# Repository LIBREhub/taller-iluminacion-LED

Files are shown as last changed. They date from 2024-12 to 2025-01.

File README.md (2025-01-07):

# Taller de iluminación LED

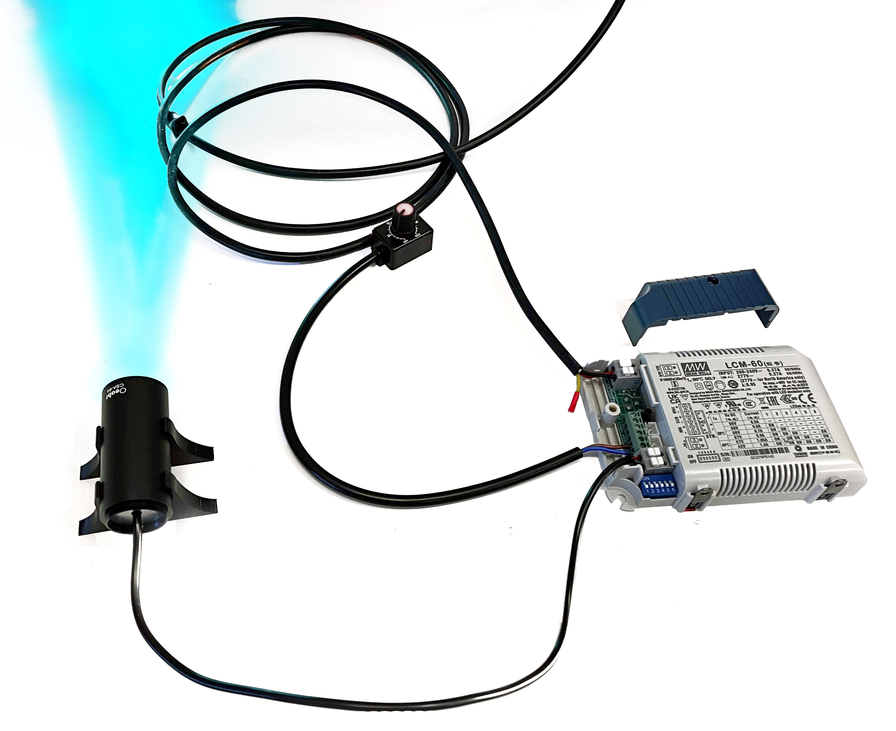
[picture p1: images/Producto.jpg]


##Arma el tuyo:
* [Componentes](Componentes.md)
* [Instrucciones de armado](Instrucciones.md)

---

##Siguenos en redes:
* [YouTube](https://www.youtube.com/@librehub), 
* [LinkedIn](https://www.linkedin.com/company/92802424), 
*   [Instagram](https://www.instagram.com/wenzellab), 
*  [Printables](https://www.printables.com/@WenzelLab/models) &  [Thingiverse](https://www.thingiverse.com/libre-hub/designs)
* [LIBREhub website](https://librehub.github.io),  
* [IIBM website](https://ingenieriabiologicaymedica.uc.cl/en/people/faculty/799-vicente-parot)

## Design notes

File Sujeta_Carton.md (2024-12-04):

#Plástico sujetador de cartón



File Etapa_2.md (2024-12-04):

##Etapa 2: Conexiones al driver

En esta etapa conectarás el cable AC del enchufe al driver y el dimmer al driver, como
muestra este diagrama:

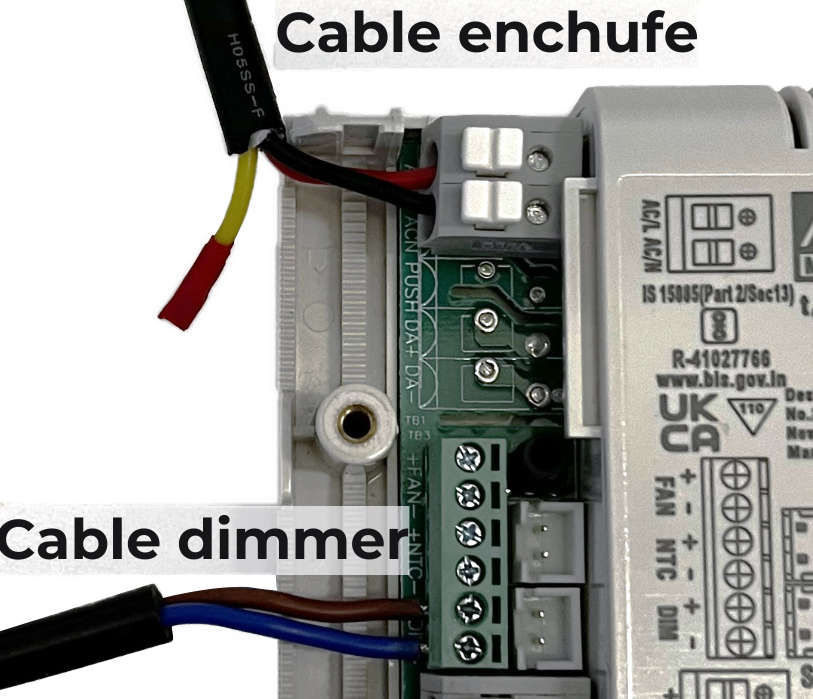
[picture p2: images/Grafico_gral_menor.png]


Como podrás notar, el cable amarillo queda libre, así que le pondremos cinta aislante por
seguridad, aunque luego le pondremos la tapa al driver de igual manera. Luego de construir
el módulo LED en la siguiente etapa, lo conectaremos al driver en la etapa 4.

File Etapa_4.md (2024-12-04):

##Etapa 4: Construir el módulo LED

Para esta etapa necesitaras pelar el cable más delgado por ambos extremos. En uno dejarás
aproximadamente 2 centímetros expuestos de los cables rojo y negro que están dentro,
exponiendo sus conductores para conectarlos al driver posteriormente. En el otro extremo,
dejarás 5 centímetros y con el conductor expuesta. Este último extremo es el que debes
introducir a la perforación del disipador de calor.

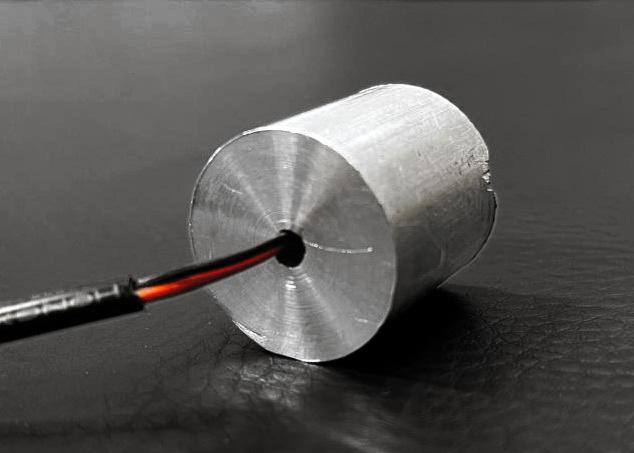
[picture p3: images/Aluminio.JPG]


Luego, vamos a soldar el LED a los cables que sobresalen del disipador. **Es muy importante
que respetes la polaridad al momento de soldar**, siguiendo este diagrama (rojo =
positivo; negro = negativo).

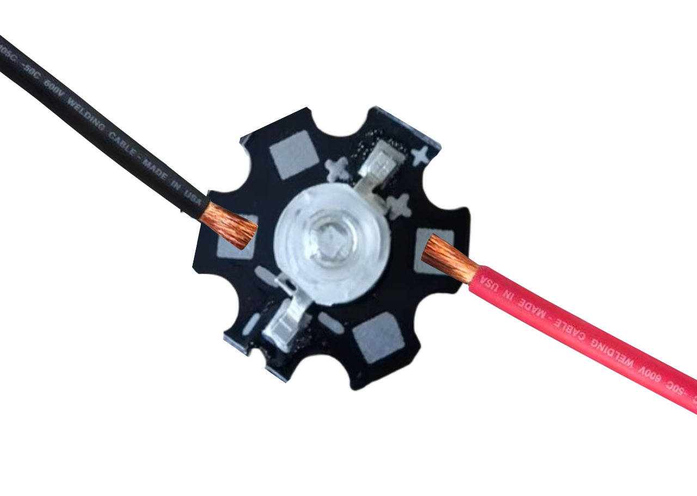
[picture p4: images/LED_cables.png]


Para soldar los cables necesitarás un cautín y estaño, los cuales te brindaremos en ese
momento.

Una vez soldado el LED, debes pegar la cinta termoconductora azul de doble contacto al
disipador, para luego pegar el LED. Para ello, cortarás dos pedazos con la forma que
sobresale fuera de la ranura del disipador, tal como se indica en la siguiente foto:

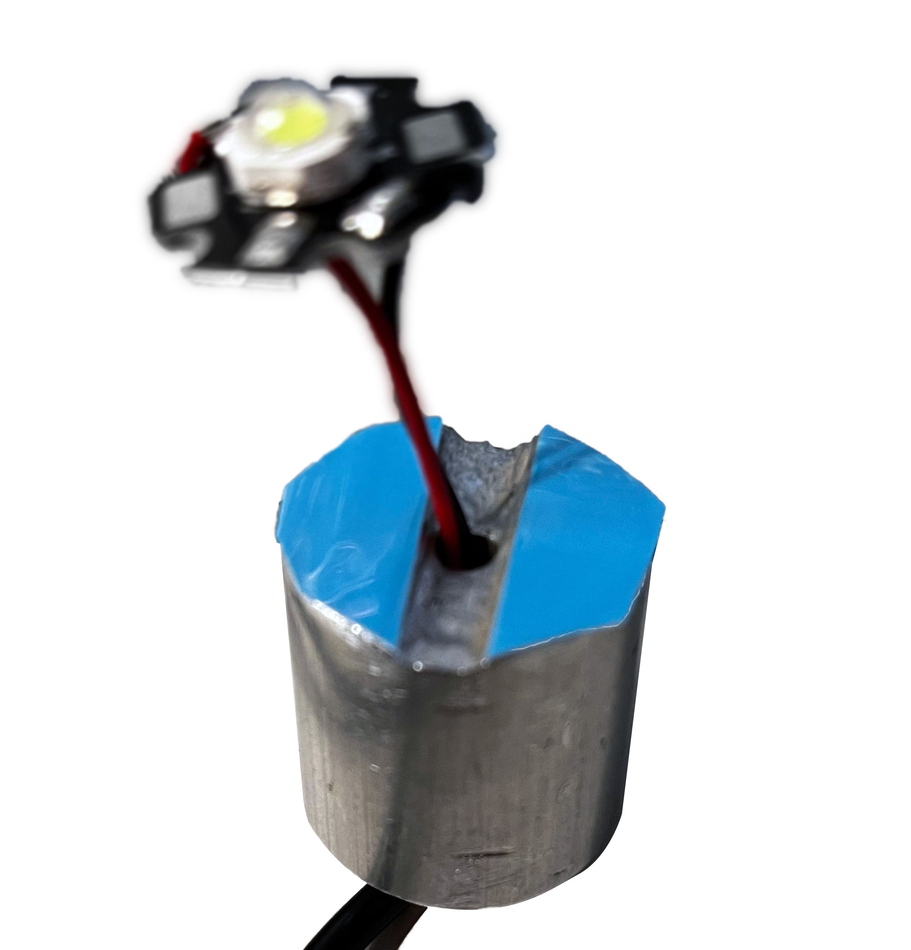
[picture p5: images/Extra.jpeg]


Luego debes **posicionar el LED en el centro**, pegarlo y presionar con fuerza, hasta tener
seguridad de que está bien unido al disipador.

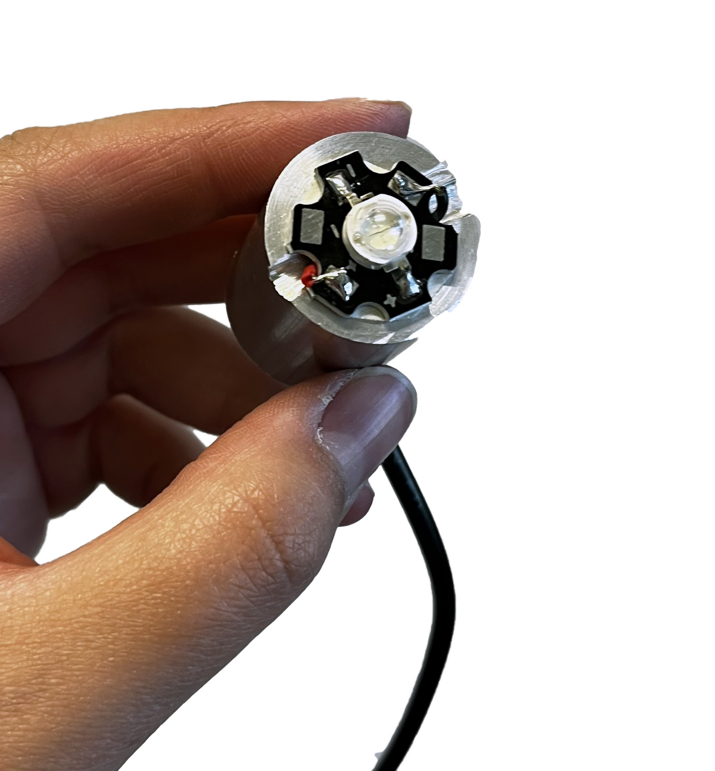
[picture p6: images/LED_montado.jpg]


Posteriormente, debes introducir todo este componente en el tubo, para luego afirmarlo con un anillo.

Para ello, debes posicionar el anillo en los topes de la herramienta que construiste en la
segunda etapa, introducirlo en el tubo y atornillar apretando (en sentido horario) hasta que
la herramienta marque 33 mm de profundidad.

Verifica que, al mover el tubo, no haya movimiento de los componentes que están dentro.

Una vez asegurado el disipador, debes atornillar otro anillo hasta una profundidad de 20 mm
de profundidad.

Luego, posicionarás en la herramienta atornilladora un anillo, un anillo separador y un lente,
con el lado convexo (redondo) hacia abajo.

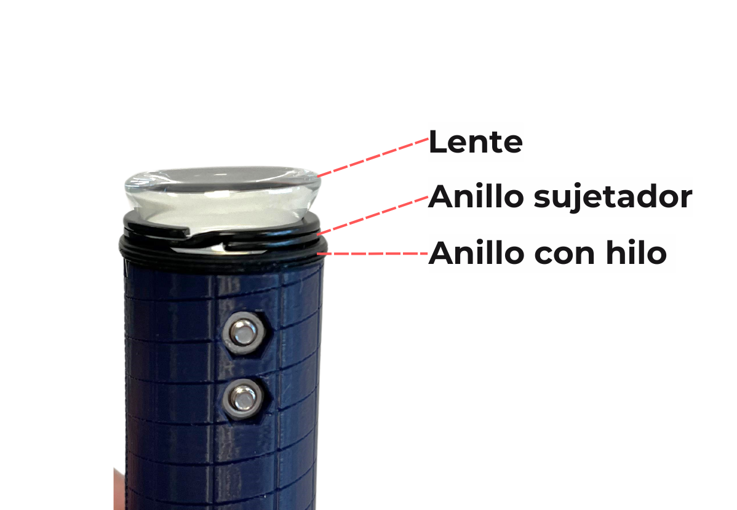
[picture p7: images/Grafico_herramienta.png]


Luego manteniendo la herramienta en su posición vertical con el lente encima, se debe
enroscar el tubo por encima de ella, hasta llegar a una profundidad de 16 mm.

Verifica que, al mover el tubo, no haya movimiento de los componentes que están dentro.

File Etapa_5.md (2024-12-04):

Etapa 5: Conectar módulo LED al driver

En esta etapa debes conectar el cable del extremo del módulo LED al driver siguiendo el
diagrama:

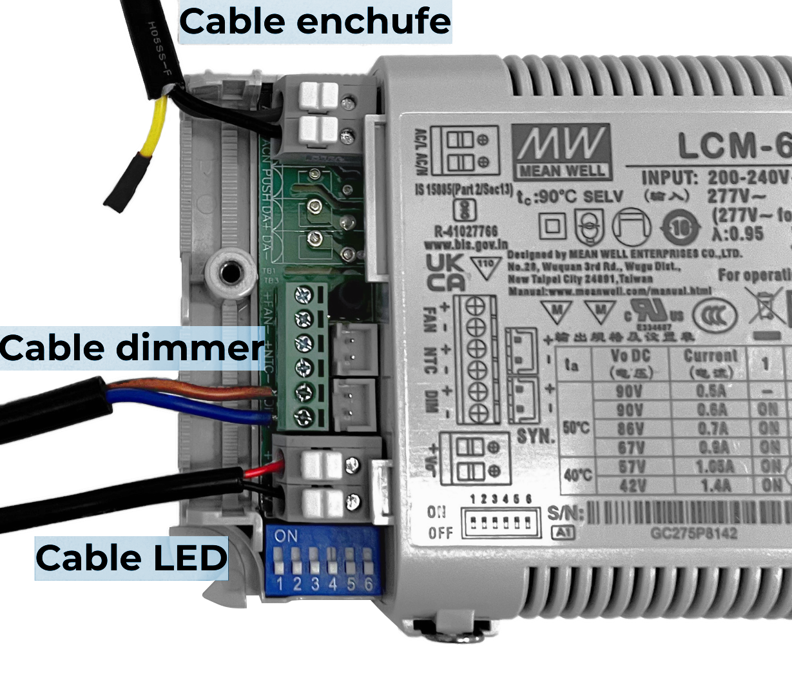
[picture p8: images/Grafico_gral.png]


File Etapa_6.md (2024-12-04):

##Etapa 6: Configurar el driver

Con el objetivo de estudiar el comportamiento de los LEDs a 1 Ampere, debes configurar los
switches del driver para lograr esta corriente máxima, siguiendo este diagrama:

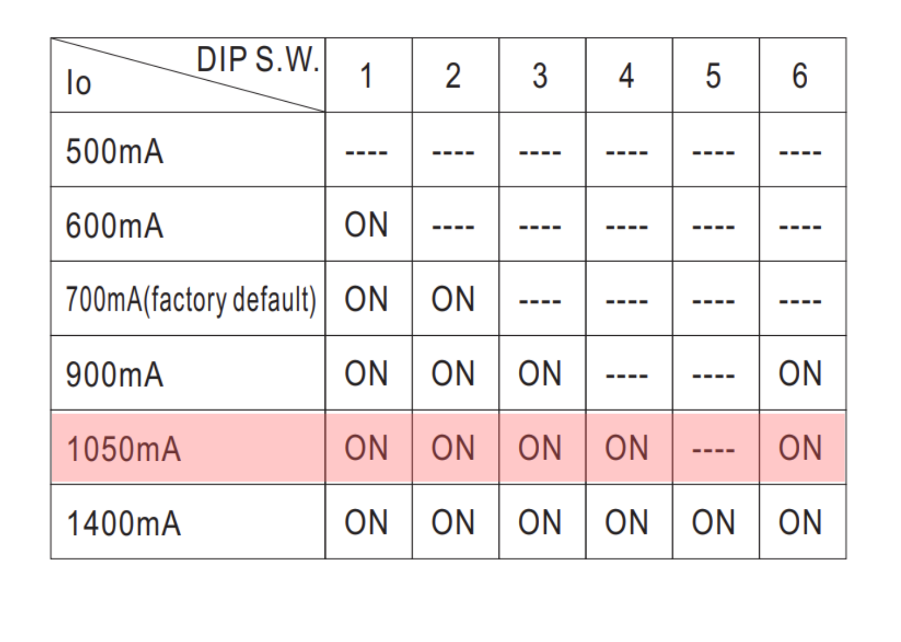
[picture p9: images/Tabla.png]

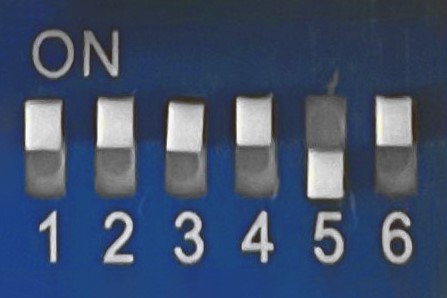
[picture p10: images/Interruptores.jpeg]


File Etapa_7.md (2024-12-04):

###Etapa 7: Conexión AC y pruebas de enfoque

Luego de verificar que todos los componentes estén bien conectados, enchufaremos el driver
a la corriente y encenderemos el led con la perilla del dimmer. Es recomendable apuntar la
luz hacia la pantalla de cartón para no causar molestias a otros grupos de trabajo que puedan
estar cerca.
¡Listo! Ahora estás listo para probar tu módulo LED



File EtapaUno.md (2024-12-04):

##Etapa 1: Ensamblar el  enchufe

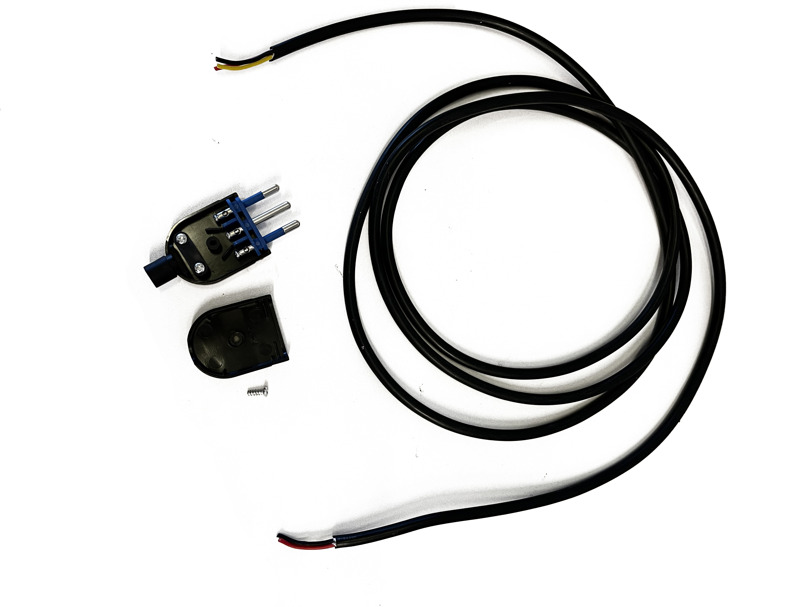
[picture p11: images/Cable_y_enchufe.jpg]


Para esto necesitarás el cable de tres conductores, el enchufe y un desatornillador. Debes
pelar el cable por ambos extremos, para dejar al exterior los 3 cables que se encuentran
dentro y sus terminales de cobre. Un extremo de ellos los conectaremos al enchufe y el otro
extremo al driver en la próxima etapa.

Para facilitar el proceso, introduce los tres cables por el inicio del enchufe y luego separa los
componentes de este, para poder atornillar libremente cada cable en su lugar, siguiendo este
diagrama:

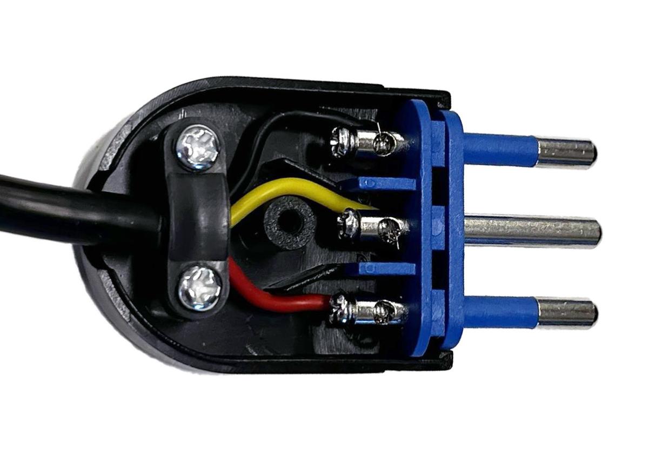
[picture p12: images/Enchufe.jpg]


Para fijar los cables, debes soltar el tornillo respectivo e introducir las fibras del cable dentro
del orificio y luego atornillas nuevamente hasta que quede apretado. Una vez finalizado,
ensambla el enchufe nuevamente.

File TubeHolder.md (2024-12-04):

#Sujetador de tubos ópticos



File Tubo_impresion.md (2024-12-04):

#Herramienta plástica para atornillar



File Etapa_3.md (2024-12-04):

##Etapa 3: Construir herramienta para asegurar elementos ópticos

Para esta etapa necesitarás el tubo de plástico dispuesto en el kit, la bolsa de tornillos y
tuercas M3, los dos atornilladores pequeños, y una llave allen 2.5 mm.

Esta herramienta servirá para enroscar anillos sujetadores dentro del tubo óptico metálico.
Es una alternativa barata a una herramienta comercial de precisión que tiene un costo más
elevado. Esta herramienta es de plástico con unos pines metálicos que permiten enroscar los
anillos.

En primer lugar, se debe romper el mango plástico de los atornilladores para dejar expuestos
los pines de metal, que se introducen en guías especiales en la punta del tubo plástico.

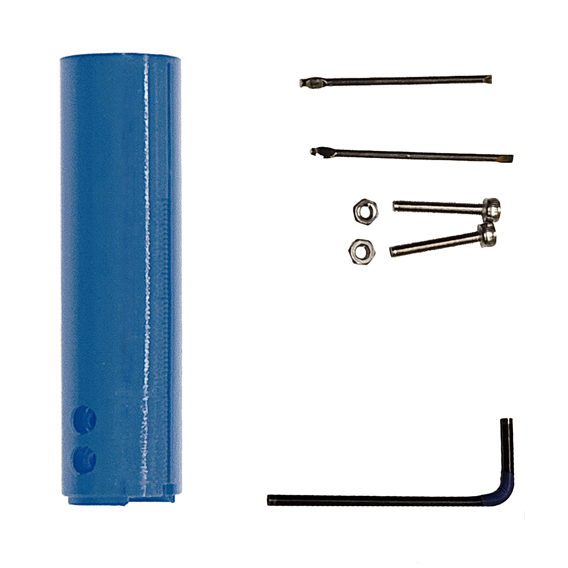
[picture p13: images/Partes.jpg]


Luego, se debe posicionar las tuercas y luego los tornillos, enroscándolos lo mínimo posible
para sostener los pines de metal en su lugar sin apretarlos. Para posicionar los pines de
metal, deben girarse en su lugar hasta que las dos paletas estén alineadas.

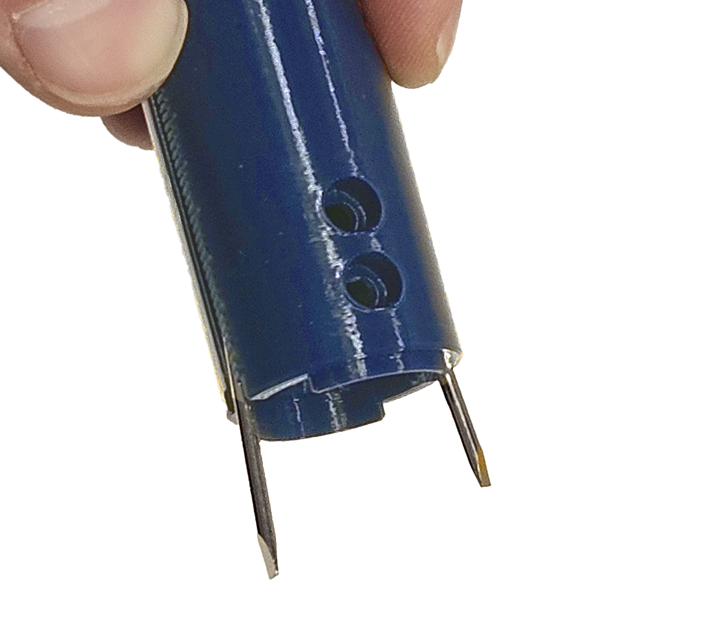
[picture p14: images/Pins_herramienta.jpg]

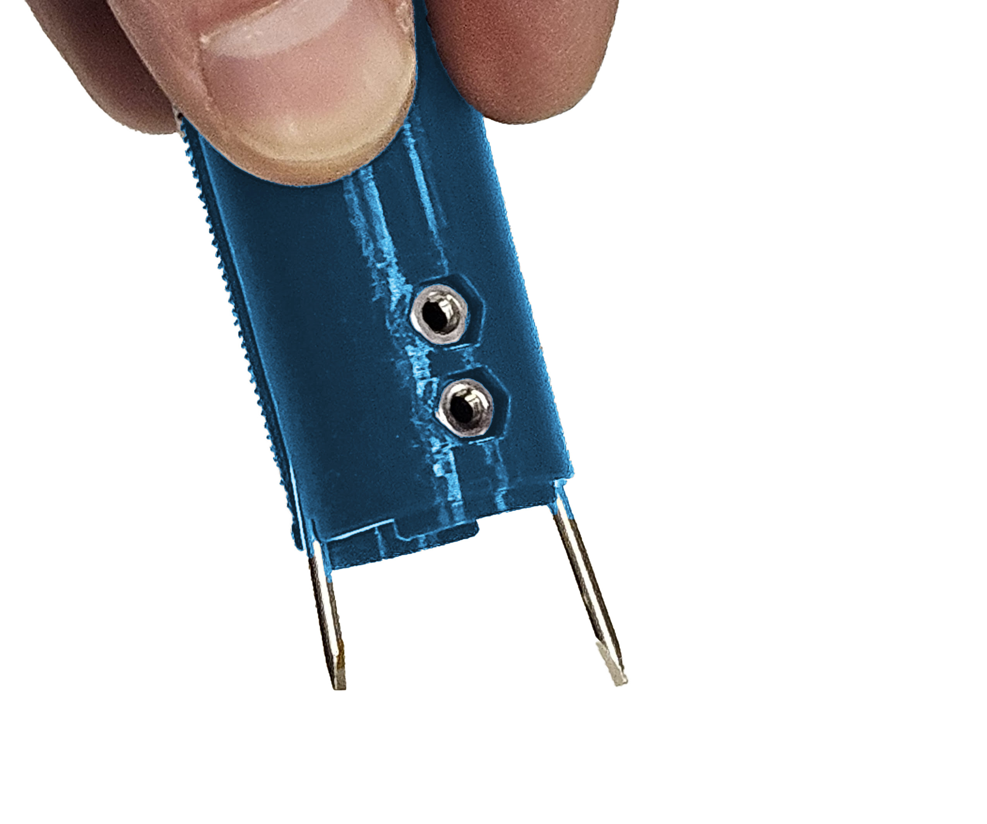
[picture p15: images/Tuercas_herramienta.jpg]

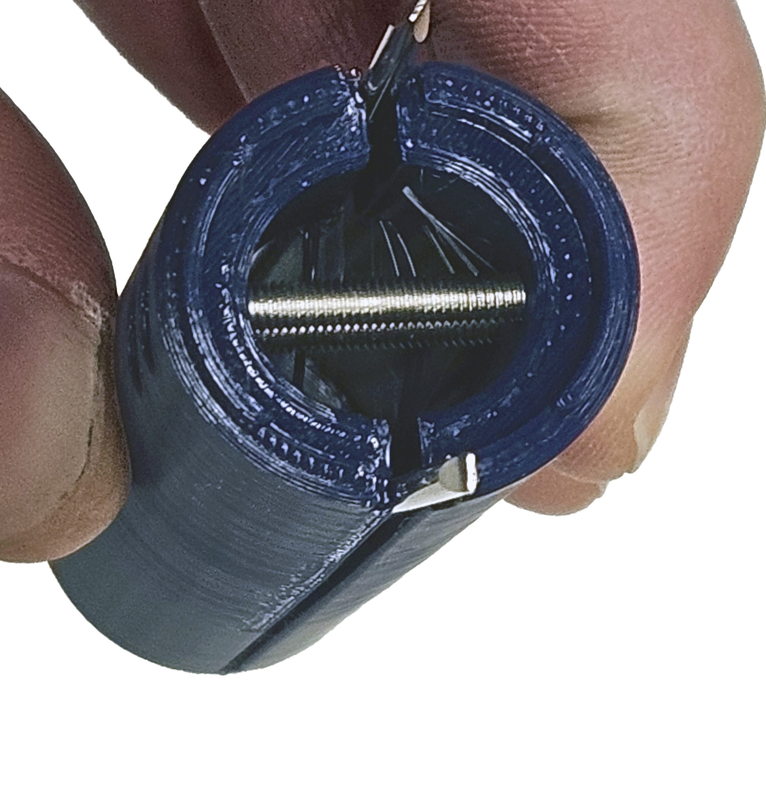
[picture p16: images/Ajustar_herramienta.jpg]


El siguiente paso es empujar los pines hacia adentro hasta que sobresalgan unos milímetros.
Para ajustar su altura exacta, usar la ranura de un anillo con hilo para empujarlo hasta el
tope. De esta forma el pin sobresale exactamente la profundidad de la ranura. Repetir el
ajuste con el otro pin.

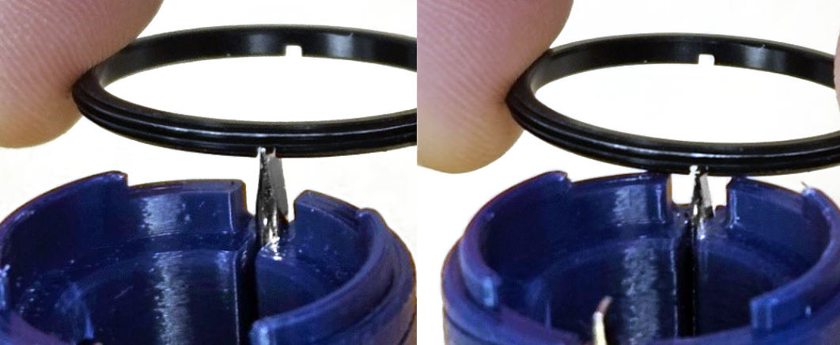
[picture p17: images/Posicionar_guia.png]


Finalmente sin mover los pines, apretar de a poco los pernos por turnos, hasta que la punta
de la herramienta sea circular y encaje con el anillo.

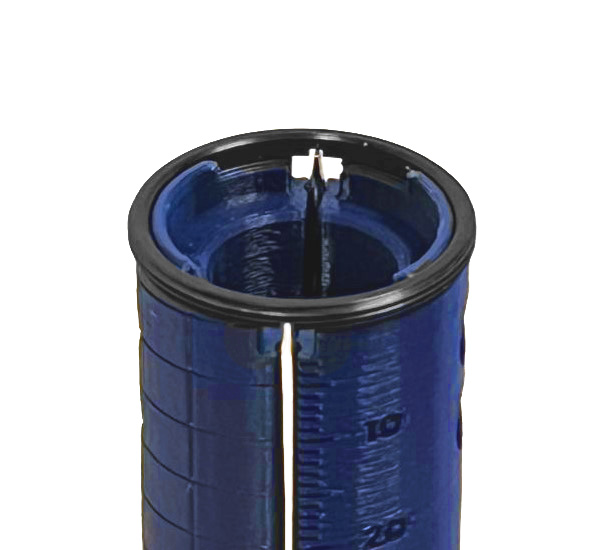
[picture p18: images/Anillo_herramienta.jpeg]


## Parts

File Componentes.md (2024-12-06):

#Componentes

El kit contiene:

|Qty| Componente|Especificaciones|Proveedor|Precio por kit (USD)|
|---|---|---|---|---|
1| Anillo separador |25mm, 10pc|[Aliexpress](https://www.aliexpress.com/item/1005006239272362.html)|$ 0.22
2| Anillos con hilo adicionales |CSK3 (4piece)|[Aliexpress](https://www.aliexpress.com/item/4001078802492.html)|$ 3.84
2| Atornilladores |Slotted, CHINA|[Aliexpress](https://www.aliexpress.com/item/1005005020176036.html)|$ 0.38
1| Cinta termo conductora |15mm, 25M, CHINA|[Aliexpress](https://www.aliexpress.com/item/4000233593859.html)|$ 0.00
1| Cable AC|3 Core 0.5mm2 20m|[Aliexpress](https://www.aliexpress.com/item/1005007451533230.html)|$ 1.62
1| Cable DC |2 Core-Black, 24 AWG, 20M|[Aliexpress](https://www.aliexpress.com/item/1005006610531349.html)|$ 0.86
1| Dimmer |Black 6Pc|[Aliexpress](https://www.aliexpress.com/item/1005006590327198.html)|$ 3.33
1| Disipador metálico mecanizado |OD25 ID4, 500mm|[Aliexpress](https://www.aliexpress.com/item/1005004060288593.html)|$ 1.43
1| Driver Mean Well LCM-60 |LCM-60|[Aliexpress](https://www.aliexpress.com/item/1005006010661416.html)|$ 26.98
1| Enchufe AC|10A plug|[Aliexpress](https://www.aliexpress.com/item/1005006063247022.html)|$ 1.26|
1| LED |With 20mm board, 3W 480nm 10pcs|[Aliexpress](https://www.aliexpress.com/item/1005007551981301.html)|$ 0.35
1| Lente|5 pieces, D25 H11 F15 |[Aliexpress](https://www.aliexpress.com/item/1005007025619408.html)|$ 1.77
1| Pantalla de cartón|80x120 cm |[Arquitectura Librería](https://www.arlib.cl/product/carton-pluma-negro-5mm-80x120cm)|$ 0.31
2| Tornillos M3 20mm cabeza hex socket |M3, 20mm|[Aliexpress](https://www.aliexpress.com/item/4000026671295.html)|$ 0.26
1| Tubo metálico con hilo y anillo |CSA-64(64mm)|[Aliexpress](https://www.aliexpress.com/item/4001078802492.html)|$ 19.9
2| Tuercas M3 |M3, 50pcs|[Aliexpress](https://www.aliexpress.com/item/1005003111431468.html)|$ 0.05
1| [Herramienta plástica para atornillar](Tubo_impresion.md)|Modelo 3D, stl|[Descarga](Tubo_impresion.md)|$ 0.27
2| [Plástico sujetador tubo](TubeHolder.md) |Modelo 3D, stl|[Descarga](TubeHolder.md) |$ 0.28
2| [Plástico sujetador de cartón](Sujeta_Carton.md) |Modelo 3D, stl|[Descarga](Sujeta_Carton.md)|$ 0.66

**Costo por kit:$ 63.86**

---

>i La informacion de los proveedores fue utilizada para el taller de [Modular Color LED Illumination for Microscopy](https://librehub.github.io/2024/06/12/led-illum-ws.html) el 11 de Octubre de 2024

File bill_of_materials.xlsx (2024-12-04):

Category | Amount | Part | Shop | Price (€) | Comment | What we have | Quantity | URL/Source
External Parts | 1 | Cylindrical lens, comar | Thorolabs | 150 | f = 100mm H = 30 mm L = 32 mm | f = 8mm f = 50 mm f = 20 mm (2x) | 1 | Link (https://www.thorlabs.com/thorproduct.cfm?partnumber=LJ1567L1)
 | 1 | Camera, monochrome, CMOS | Daheng | 350 |  |  | 1 | Link (https://www.machinevisionkamera.de/USB3-Bildverarbeitungskamera-12.2MP-Monochrome-Sony-IMX226-MER2-1220-32U3M)
 | 1 | Focusing stage, micrometer, motorized (NEMA12) | China | 100 |  |  | 1 | Haoran
 | 1 | 10x objective, NA0.3, long-working distance | USA | 250 | 10x and NA 0.3 | 100x, NA1.25 100x NA1.4 20x NA0.5 12.5x NA? 10x NA0.25 is being used(yellow one) | 1 | Link (https://bolioptics.com/10x-infinity-corrected-plan-achromatic-microscope-objective-lens-bm05073332/)
 | 1 | XYZ stage, AliExpress, micrometer | China | 250 |  |  | 1 | Link (https://de.aliexpress.com/item/33013923564.html?gatewayAdapt=glo2deu)
 | 3 | Motor for stage | China | 80 |  |  | 3 | Link (https://eckstein-shop.de/PololuStepperMotorNEMA11Bipolar200StepsRev28C39732mm38V067APhase)
 | 1 | Tube lens | China | 200 | f = 100mm F3.5 | Lots of lenses does not have specifications | 1 | Link (https://www.berrybase.de/100mm-teleobjektiv-c-mount)
 | 1 | Fiber laser | China | 200 | ?? | https://www.thorlabs.com/thorproduct.cfm?partnumber=P1-460A-FC-5 This is the one that we have, dont know if it works | 1 | Haoran
 | 1 | Mirror | PGI | 5 | Simple small mirror | We have some thorlabs mirrors | 1 | Link (https://pgi-shop.de/vorderflaechen-glasspiegel-30-0-x-40-0-mm/)
 | 1 | 4x objective lens finite | China | 10 | 4x | 4x (x2) | 1 | Haoran
 | 1 | Fiber Collimator | China | 100 |  | Could we build it with lenses? | 1 | Haoran
 | 14 | Baseplates | openUC2 | 3 |  |  | 14
 | 8 | Cubes | openUC2 | 5 |  |  | 10
 | 1 | Solid baseplate (aluminium) | openUC2 | - |  |  | 1
 | 1 | Excitation filter (Thorlabs) | Thorolabs | 120 | 500 nm cut-on | 500 nm long pass (CORION) | 1 | Link (https://www.thorlabs.com/thorproduct.cfm?partnumber=FELH0500)
Inserts (3D printable?) | 1 | Fiber Collimator Mount | openUC2 | 5 |  |  | 1
 | 1 | Cylindrical Lens Mount | openUC2 | 5 |  |  | 1
 | 1 | 45° Mirror Mount (kinematic) | openUC2 | 25 |  |  | 1
 | 1 | RMS Lens Mount | openUC2 | 5 |  |  | 1
 | 1 | Sample mount (printed) | openUC2 | 30 |  |  | 1
 | 1 | Base for XYZ Stage | openUC2 | 2 |  |  | 1
 | 1 | Sample mount for XYZ Stage | openUC2 | 15 |  |  | 1
 | 1 | Holder for Z-stage motorized | openuc2 | 30 |  |  | 1
 | 1 | Holder for Tubelens | openUC2 | 10 |  |  | 1
 | 1 | Holder for UC2 Electronics | openUC2 | 30 |  |  | 1
Electronics | 1 | Electronics, Powersupply, Stepper driver | openUC2 | 100 |  |  | 1
 | 2 | USB cables (camera, micro) | Germany | 60 |  |  | 2
 | 1 | Playstation Controller | Germany | 50 |  |  | 1
 | 1 | Box + Foam insert | openUC2 | 100 |  |  | 1 | Link (https://www.contorion.de/p/stier-universal-outdoor-koffer-flugtauglich-lxbxh-418x317x151-mm-86520627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)
Labour & Shipping | - | Labour + Shipping | - | 500 |  |  | 1

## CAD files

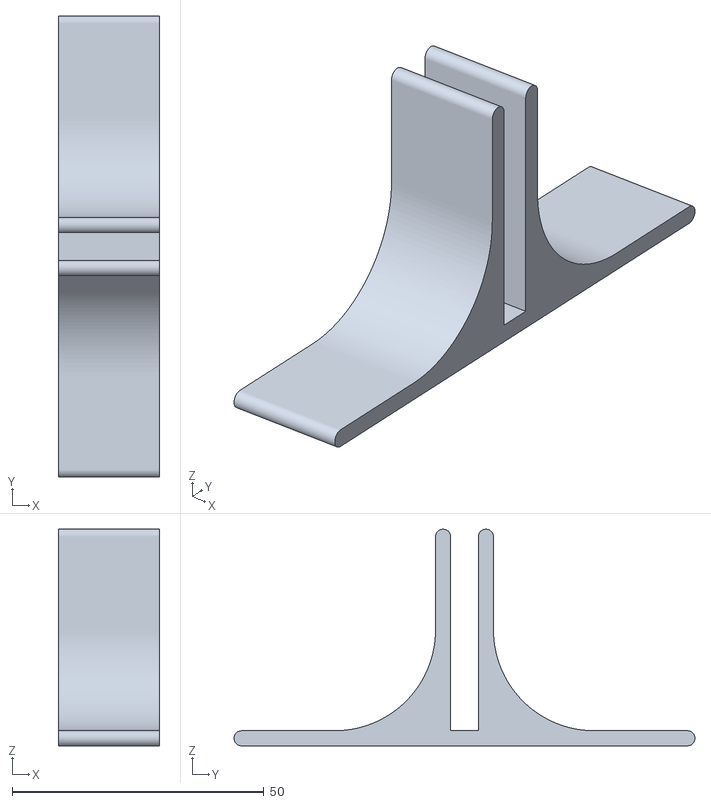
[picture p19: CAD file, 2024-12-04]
models/Carboard_Holder.stl
20.0 x 91.5 x 43.0

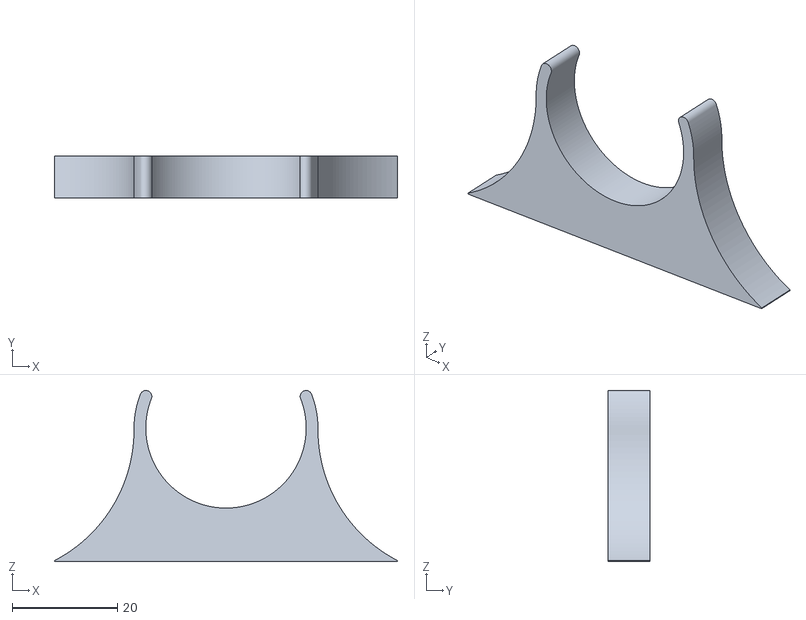
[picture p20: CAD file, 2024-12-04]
models/Tube_Base.stl
65.3 x 8.00 x 32.5

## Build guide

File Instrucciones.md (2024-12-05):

#Instrucciones de armado



##Etapas
####1)  [Ensamblar el  enchufe](EtapaUno.md)
####2) [Conexiones al driver](Etapa_2.md)
####3) [Construir herramienta para asegurar elementos ópticos](Etapa_3.md)
####4) [Construir el módulo LED](Etapa_4.md)
####5) [Conectar módulo LED al driver](Etapa_5.md)
####6) [Configurar el driver](Etapa_6.md)
####7) [Conexión AC y pruebas de enfoque](Etapa_7.md)

>!! Es muy importante NO conectar el driver a la corriente AC hasta asegurar que todos los otros componentes están conectados correctamente y firmemente, de lo contrario se corre el riesgo de quemar el LED.

>! Este driver usa alimentación de 200–250 VAC. Para usarlo con alimentación AC de 110 V es necesario añadir un transformador de alimentación AC 110V a 220V. El enchufe para conectar el driver a alimentación AC se puede intercambiar según las instrucciones de ensamblaje en este documento.

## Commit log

2024-12-04 Deploying to main from @ af403879e69dc80f1779104e8ebcd2e1a852e190 🚀
2024-12-04 Deploying to main from @ 851f9f270cf0c9ab4e67e6a6120c7d38b1b8802f 🚀
2024-12-04 Deploying to main from @ 091a5a3f5b880c286e6ed4fc659cd7fa523b3e4c 🚀
2024-12-04 Deploying to main from @ fabb954d347ed326db11f591292e3664dcd1076c 🚀
2024-12-04 Deploying to main from @ 22ea89e5f874a28074f1c4a60812bbd88d7d3d61 🚀
2024-12-05 Deploying to main from @ 444231220a868f6b8667ec79435825a1785126b7 🚀
2024-12-05 Deploying to main from @ d6ca3fcc000021a811b5d03e03d66fb51b8ed0da 🚀
2024-12-06 Deploying to main from @ d20d13beda9c635700d19dcf335a6aeb6e073db6 🚀
2025-01-07 Deploying to main from @ 36d302a67c5d28b76c1b3cab5f26d7b1f6e67b9a 🚀
